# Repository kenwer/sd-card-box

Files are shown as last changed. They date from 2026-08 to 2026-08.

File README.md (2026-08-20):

# SD Card Box
Design for a parametric case to carry (many) SD cards. Intended for FDM 3D printing.

**License:** [CC BY-SA 4.0](http://creativecommons.org/licenses/by-sa/4.0/)  
**Author:** Ken Werner

## Overview
The case consist of base with plus a snap-locking lid, printed as two parts on a shared hinge pin. Each card sits in its own tilted slot, angled toward the hinge so it stands at the same angle the lid needs when it swings shut. The two parts can be printed without support. A piece of 1.75 mm Filament can be used to connect the hinges.

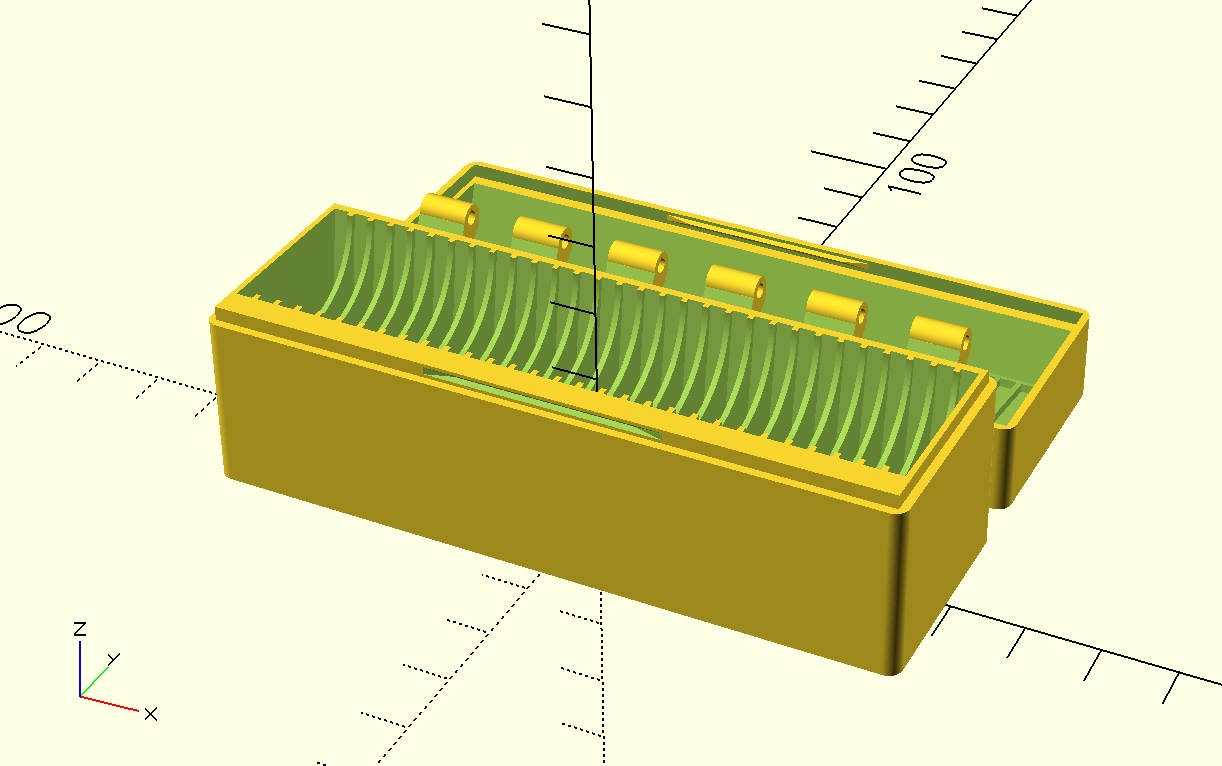
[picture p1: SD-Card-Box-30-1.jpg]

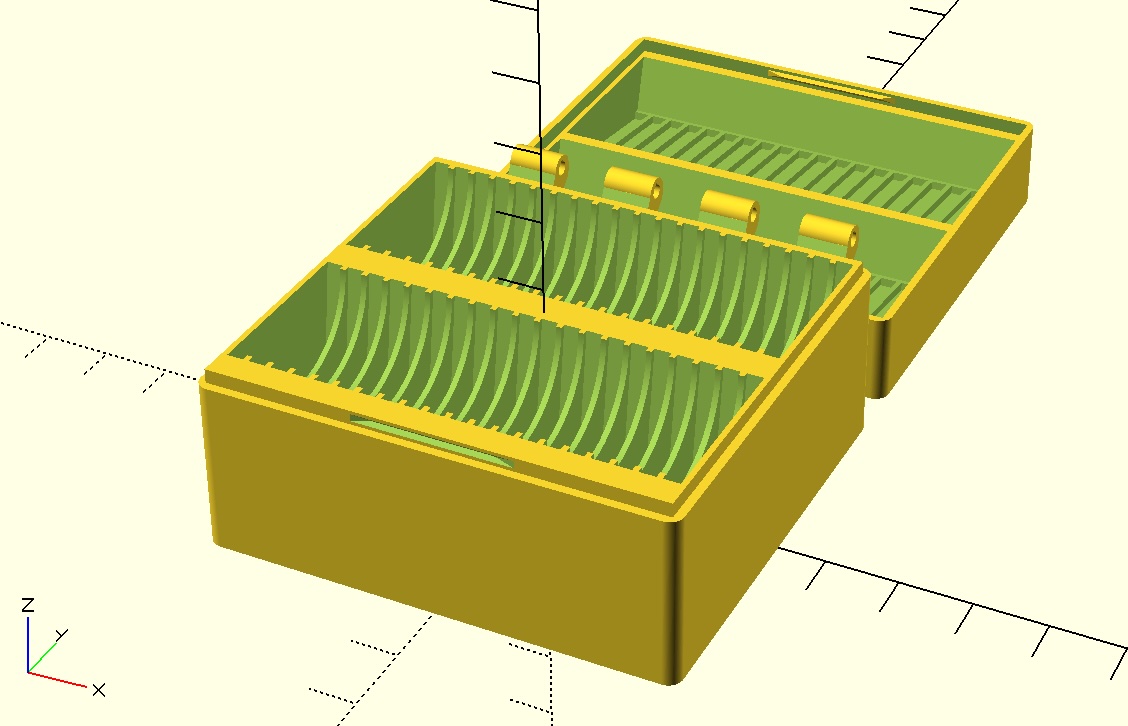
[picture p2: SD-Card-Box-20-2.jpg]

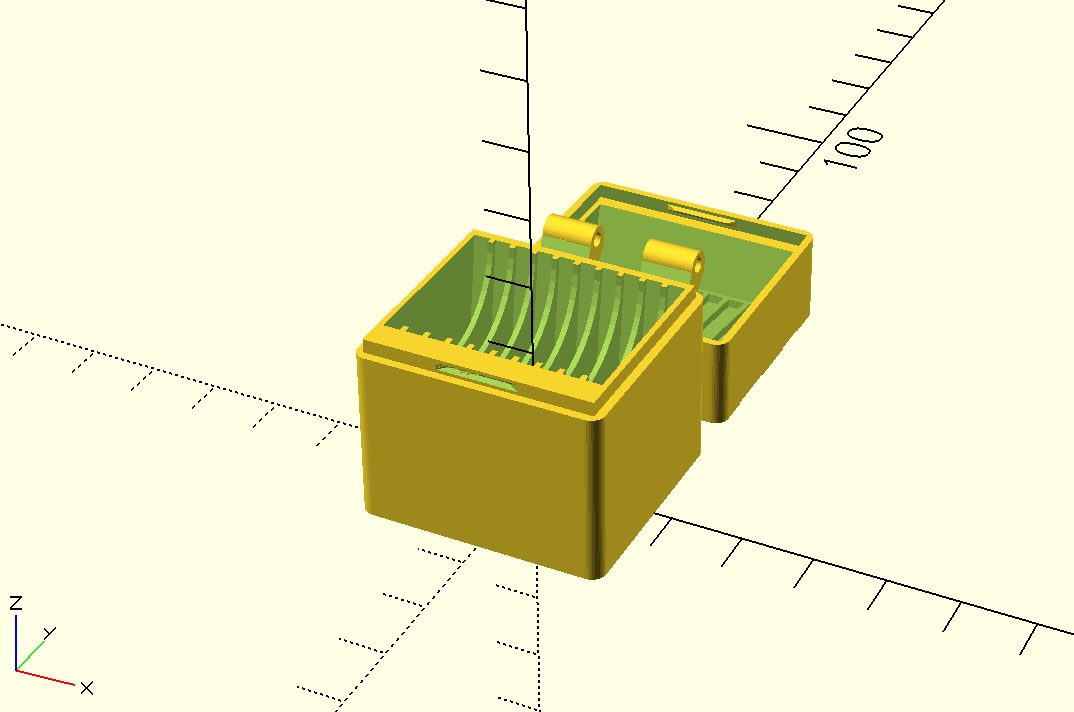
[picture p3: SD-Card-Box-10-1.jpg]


## Requirements
- [OpenSCAD](https://openscad.org/)
- [BOSL2](https://github.com/BelfrySCAD/BOSL2) library

## Usage
Open `sd-card-box.scad` in OpenSCAD. The preview shows the base and the lid (with engraved text) side by side. To export a part for printing, comment out the one you don't need and export as STL (F6 to render, then File -> Export -> STL or 3mf).

### Key parameters
| Parameter | Default | Description |
|---|---|---|
| `num_sd_slots_per_row` | 30 | Slots per row, stacked along the hinge axis |
| `num_sd_slot_rows` | 1 | Rows stacked in the depth direction |
| `spacing` | 0.8 mm | Gap between slots |
| `sd_clearance` | 0.28 mm | Extra room added to each slot so a card drops in freely |
| `card_tilt` | 8°| Angle slots (and the lid pockets) lean toward the hinge |
| `wall_thickness` | 1.2 mm | Outer shell and lid thickness |
| `lid_catch_depth` | 1.2 mm | How deep the lid's per-card pockets grip the card tip |
| `lock_height` / `lock_socket_clearance` | 0.4 mm / 1.05 | Snap-lock ridge height and socket oversize |
| `hinge_offset` / `hinge_pin_raise` | 3 mm / 2 mm | Hinge pin position relative to the shell |
| `case_text1` / `case_text2` | card count / free text | Text engraved into the lid |

## Printing Notes
- Print both the base and the lid as oriented in the preview (open side up). No supports needed as the hinge knuckles use a teardrop profile so they print bridge-free.
- If the lid snaps too tight or too loose, adjust `lock_height` or `lock_socket_clearance`.
- If cards are hard to insert or fall out too easily, adjust `sd_clearance`.

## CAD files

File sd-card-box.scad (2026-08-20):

/*
Box for carrying (many) SD-Cards

Author: Ken Werner

The model is intended for 3D printing.

This work is licensed under the licensed under the CC BY-SA 4.0 license. The full text of the Creative Commons Attribution-ShareAlike 4.0 International License can be found at: http://creativecommons.org/licenses/by-sa/4.0/
*/

include <BOSL2/std.scad>
include <BOSL2/hinges.scad>

$fn = $preview ? 40 : 220;
nothing = 0.01;

// Layout
num_sd_slots_per_row = 30; // slots per row (cards stacked along the hinge)
num_sd_slot_rows     = 1;  // rows stacked in the depth direction
spacing              = 0.8; // gap between slots

// Card (SD spec + fit)
sd_clearance = 0.28; // slots this much larger than the card so it drops in; 0.3 -> a bit loose
// SD card dimensions are 32.0 x 24.0 x 2.1 mm
sd_depth  = 2.1  + sd_clearance; // card thickness -> spacing direction within a row
sd_width  = 24.0 + sd_clearance; // card width -> spacing direction between rows
sd_height = 32.0 + sd_clearance; // card height -> sticks up out of the slot
card_tilt = 8; // degrees the slots lean toward the hinge

// Shell / lid
wall_thickness      = 1.2; // outer shell and lid thickness
shell_height_offset = 2;   // outer shell stops this far below the inner base so the lid can overlap it
outer_case_rounding = 2.0;
lid_catch_depth = 1.2; // how deep the lid's per-card slots grip the card tip
// Lid snap lock (triangular ridge on the lid clicks into a socket in the base)
lock_height           = 0.4;  // how far the snap-lock ridge stands out (bigger = stiffer click)
lock_socket_clearance = 1.05; // base socket is oversized by this factor so the ridge snaps in

// Hinge
hinge_offset = 3; // horizontal (Y) pin offset behind the shell
// The lid closes on a circular arc about the pin. With the pin at the shell top
// (~10mm below the card tips) that arc slides sideways as it drops, so the lid
// pockets jam against the card corners
hinge_pin_raise = 2; // lifts the pin toward the card tips
hinge_arm       = 1; // leaf extension
hinge_chamfer   = 1.5;

// Engraved text
case_text1  = str(num_sd_slots_per_row * num_sd_slot_rows, " SD-Cards");
case_text2  = "some more text";
text_height = 0.25; // height of engraved text
font_sz     = 8;
font        = "DIN Condensed:style=Bold";


// Computed vars from the parameters above, don't edit

// Bounding-box reach of a tilted SD-Card in each axis. A card tilted by card_tilt no
// longer stands upright in its slot: it sweeps a bigger envelope in the tilt (Y-Z) plane.
card_env_y = sd_width * cos(card_tilt) + sd_height * sin(card_tilt); // Y (rows/depth) reach
card_env_z = sd_width * sin(card_tilt) + sd_height * cos(card_tilt); // Z (height) reach

// Centre-to-centre pitch of the slot grid, gap included
slot_pitch = sd_depth  + spacing; // along the hinge axis (within a row)
row_pitch  = card_env_y + spacing; // across the depth direction (between rows)

// Case shell. case_length is the hinge axis: cards are stacked thin-side (sd_depth) along
// it, so the tight fit lands in the hinge-parallel direction, which the closing arc leaves
// undisturbed. The rows (card width, sd_width) run across the depth direction.
case_height       = card_env_z * 0.75; // 25 % uncovered to be able to pull out cards
case_length       = num_sd_slots_per_row * slot_pitch + spacing;
case_width        = num_sd_slot_rows * row_pitch + spacing;
outer_case_height = case_height - shell_height_offset; // height of the outer shell
lid_height        = card_env_z - outer_case_height + spacing + wall_thickness;

// Lid snap-lock profile (trapezoid shared by the lid ridge and the base socket)
lock_width1 = case_length/3; // wide end of the lock profile
lock_width2 = case_length/4; // narrow end of the lock profile

// Hinge sizing
hinge_length = case_length * 0.9;
hinge_segs   = max(2, round(hinge_length / 7)); // knuckle count, sized for ~7mm long knuckles

// Rotates its children about the card's own centre
module card_tilt_frame() {
  up(card_env_z/2) xrot(-card_tilt) down(sd_height/2) children();
}

// The snap-lock trapezoid: a ridge on the lid clicks into a socket in the base
module lock_ridge(h, scale=1) {
  prismoid(size1=[lock_width1*scale, 1*scale],
           size2=[lock_width2*scale, 0],
           h=h, orient=BACK);
}

// Grid of SD-card-shaped holes, used to cut slots in both the base and the lid
module sd_card_holes(z=0) {
  up(z)
    grid_copies(spacing=[slot_pitch, row_pitch], n=[num_sd_slots_per_row, num_sd_slot_rows])
      card_tilt_frame()
        cuboid([sd_depth, sd_width, sd_height], anchor=BOT);
}

module draw_case_base() {
  // A tilted card's lowest corner lifts this far off the floor. The finger groove uses it
  // to find where the card's centreline crosses the case top.
  tilt_lift_z = sd_width / 2 * sin(card_tilt);

  diff(){
    // Inner base case
    cuboid([case_length, case_width, case_height], anchor=BOT);

    // Cut holes for the SD cards, tilted toward the hinge so the card stands at
    // the same angle the lid needs when it swings shut on its arc
    tag("remove") sd_card_holes(spacing);

    // Cut a groove across each row so the cards are easy to grab and pull out.
    tag("remove")
      ycopies(spacing=row_pitch, n=num_sd_slot_rows)
        card_tilt_frame()
          up((case_height - tilt_lift_z) / cos(card_tilt))
            xcyl(l=case_length - 2*spacing, d=sd_width - 2*spacing);

    // Lid lock socket (oversized copy of the ridge so it snaps in 0.1 deeper than the ridge so the tip seats without bottoming out)
    tag("remove") fwd(case_width/2) up(case_height-1.0)
      lock_ridge(h=lock_height+0.1, scale=lock_socket_clearance);


    // Outer base case (shell with rounding)
    rect_tube(isize=[case_length, case_width], wall=wall_thickness, h=outer_case_height, rounding=outer_case_rounding, anchor=BOT)
    // Add hinge (pin raised toward the card tips so the lid closes without binding)
    position(TOP+BACK) up(hinge_pin_raise) orient(anchor=BACK)
        knuckle_hinge(length=hinge_length, segs=hinge_segs, offset=hinge_offset, arm_height=hinge_arm, round_bot=1.0, teardrop=true, pin_diam=2, in_place=false);

    // If the height base of the case is low, the hinge might stick out at the bottom, so we cut that
    tag("remove") back(case_width/2) down(nothing) cuboid([case_length, 10, 5], anchor=TOP);

    // Bevel the top corners of the raised hinge mount so the closing lid clears them on its arc
    if (hinge_chamfer > 0) {
      tag("remove")
        back(case_width/2+wall_thickness/2) up(outer_case_height+nothing)
          prismoid(size1=[case_length+nothing, wall_thickness],
                    size2=[case_length+nothing, wall_thickness + hinge_offset/2], // TODO: currently only works with hinge_offset=3
                    shift=[0, 0.25], h=hinge_pin_raise+nothing, anchor=BOT);
    }
  }
}

module draw_case_top() {
  difference(){
    draw_case_lid();
    down(nothing)
      color("Grey", 1) xflip() engrave_text();
  }
}

module draw_case_lid() {
  lid_clearance=0.1;
  // Outer shell of the lid
  rect_tube(isize=[case_length+2*lid_clearance, case_width+2*lid_clearance], wall=wall_thickness-lid_clearance, h=lid_height, rounding=outer_case_rounding, ichamfer=0, anchor=BOT)
  position(TOP+BACK) down(hinge_pin_raise) orient(anchor=BACK)
    // Add hinge
    knuckle_hinge(length=hinge_length, segs=hinge_segs, offset=hinge_offset, arm_height=hinge_arm, round_bot=0.25, teardrop=true, pin_diam=2, inner=true, in_place=false);

  // Fill gap created by the rect_tube with lid_clearance above
  rect_tube(isize=[case_length, case_width], wall=wall_thickness, h=card_env_z-case_height, rounding=outer_case_rounding, ichamfer=0, anchor=BOT);

  // SD card slots for the lid. Besides the snug slots (sd_card_holes), each row gets a
  // loose trough that wraps the card tips so they can follow the hinge's arc without
  // binding as the lid swings shut.
  lid_pocket_height = card_env_z-outer_case_height - wall_thickness - lid_catch_depth;
  trough_len   = case_length - 2*spacing;  // full row length, along the hinge axis
  trough_w     = sd_width + 2*spacing;      // loose fit around the card width
  trough_h     = lid_pocket_height + card_env_z*sin(card_tilt); // height it rises in the tilted frame
  // Over that rise the hinge-side wall must lean out by a further card_tilt to clear the
  // swinging tip: widen the top by trough_flare and shift half of it, so only the
  // hinge-side wall leans (by card_tilt) while the far wall stays vertical.
  trough_flare = trough_h * tan(card_tilt);

  difference(){
    cuboid([case_length, case_width, card_env_z-outer_case_height], anchor=BOT);

    // The lid folds 180° about the hinge to close
    yflip() {
      up(wall_thickness)
        sd_card_holes(0);
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
